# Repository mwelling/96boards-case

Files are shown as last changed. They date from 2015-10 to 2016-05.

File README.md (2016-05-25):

# 96boards-case

Files for making cases for 96Boards CE with 3D printers.

## File list

Open scad file, fits 96Boards CE

	96board-case.scad

STL file, fits 96Boards CE

	96board-case.stl

Open scad file, fits 96Boards CE with Mezzanine board

	96board-ce-mezzanine.scad

STL file, fits 96Boards CE with Mezzanine board

	96board-ce-mezzanine.stl

gcode file exported from stl file, fits 96Boards CE with Mezzanine board

Used for MUTOH MF-2000

	96board-ce-mezzanine.gcode

x3g file exported from stl file, fits 96Boards CE with Mezzanine board

Used for MakerBot Replicator 2X

	96board-ce-mezzanine.x3g

## Images

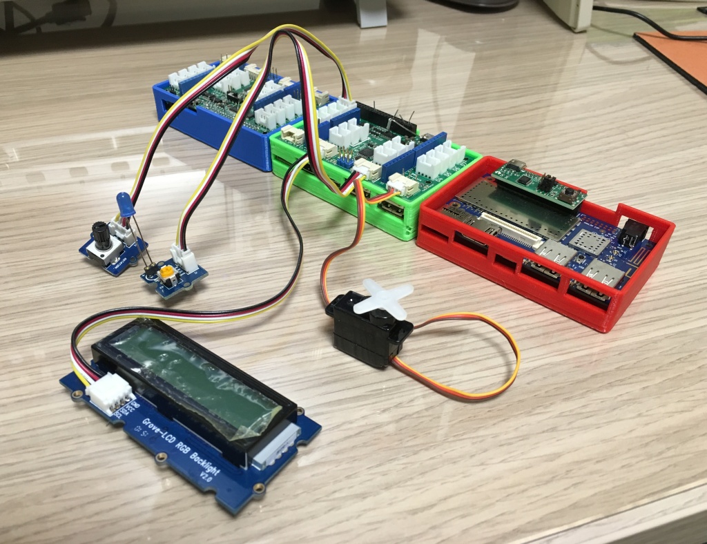
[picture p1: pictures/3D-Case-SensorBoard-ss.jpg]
All three cases

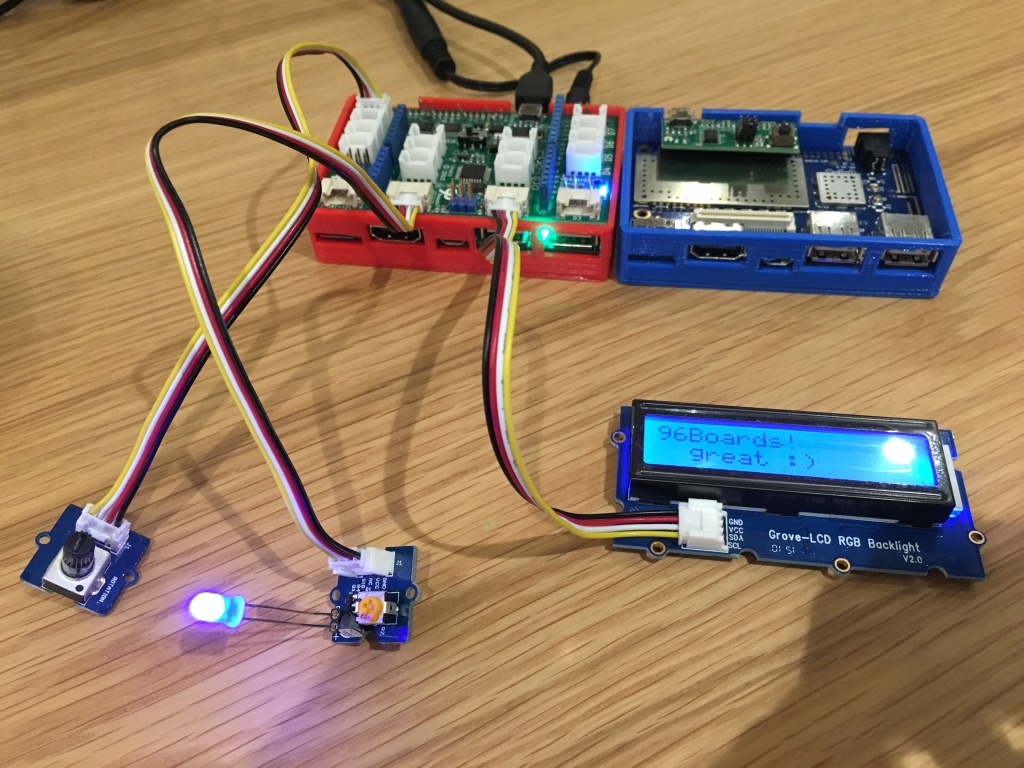
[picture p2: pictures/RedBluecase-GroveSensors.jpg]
With Grove Sensors

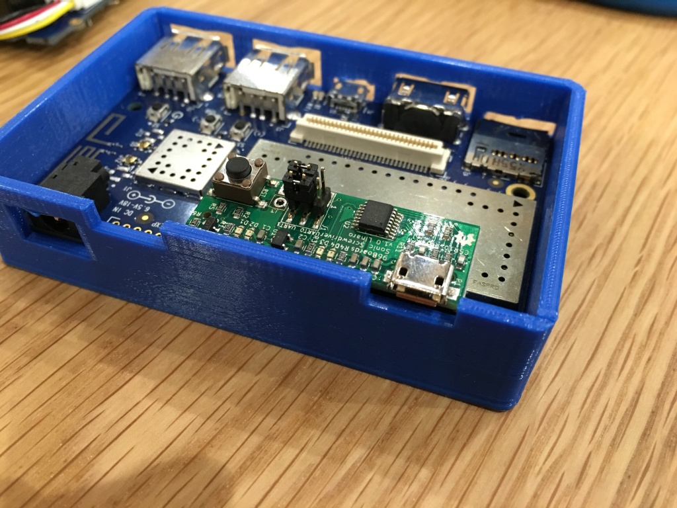
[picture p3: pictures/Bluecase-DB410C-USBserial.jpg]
USB-Serial-Blue

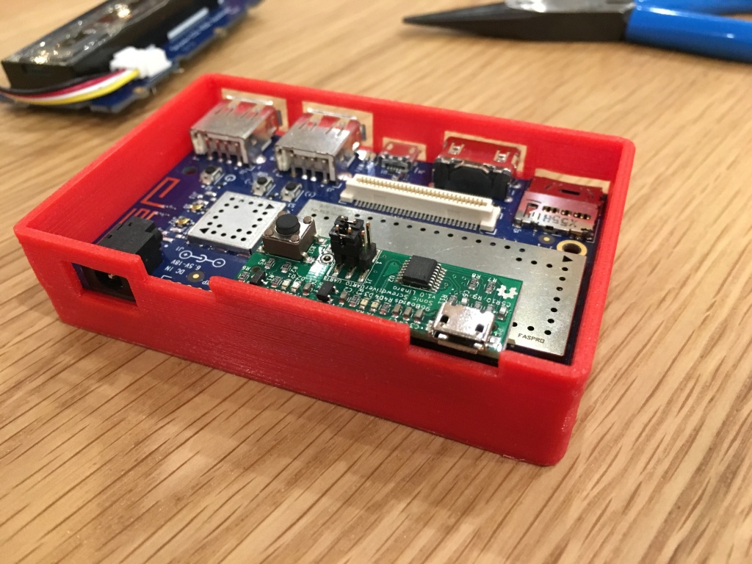
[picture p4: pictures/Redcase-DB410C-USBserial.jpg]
USB-Serial-Red

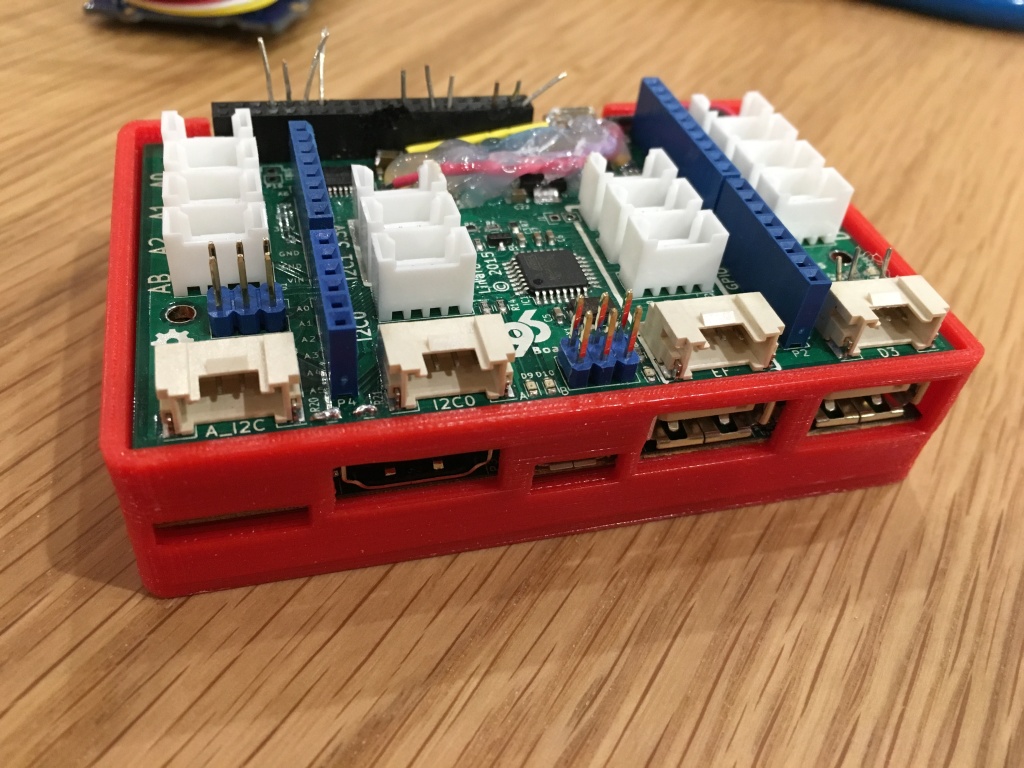
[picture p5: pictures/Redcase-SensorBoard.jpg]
SensorBoard

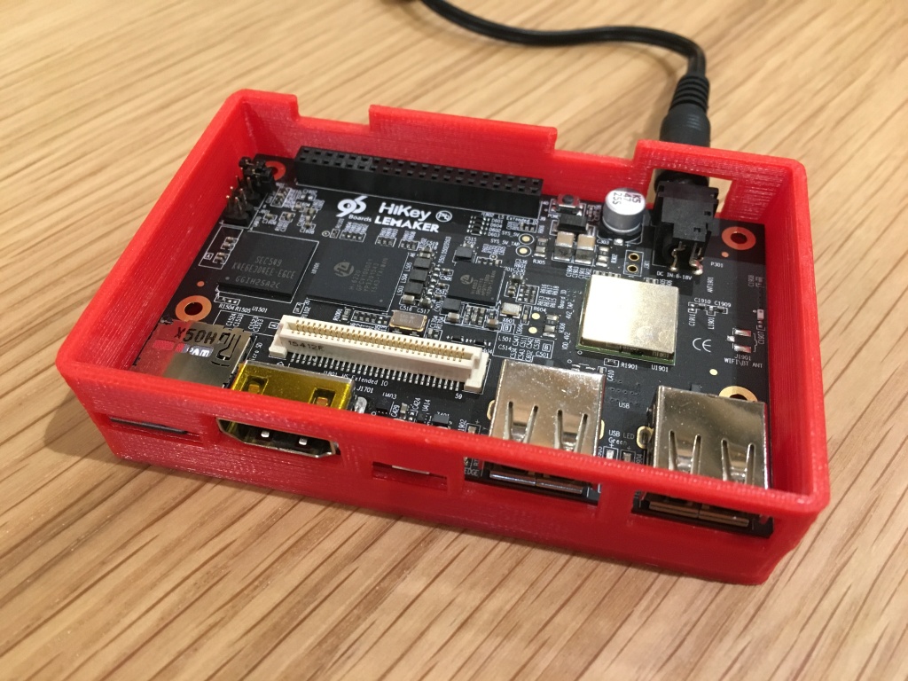
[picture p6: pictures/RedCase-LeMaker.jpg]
Red


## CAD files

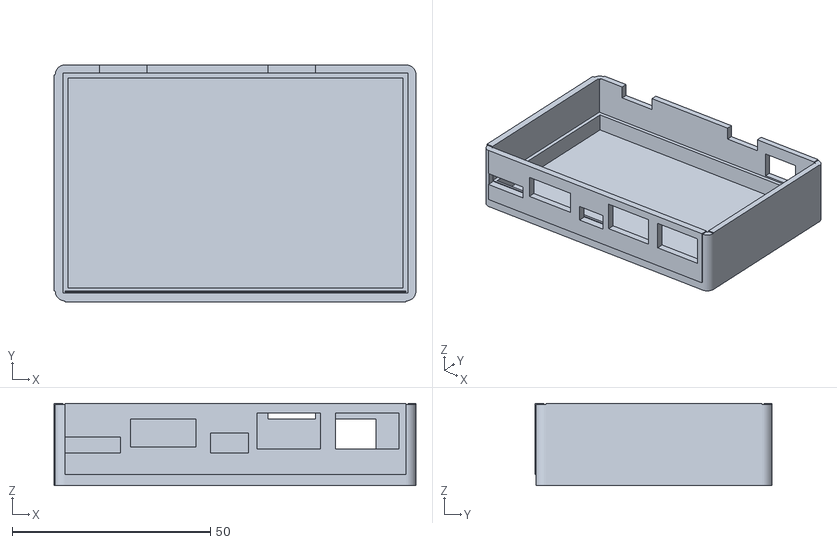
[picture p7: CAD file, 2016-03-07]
96board-ce-mezzanine.stl
91.4 x 59.9 x 20.8

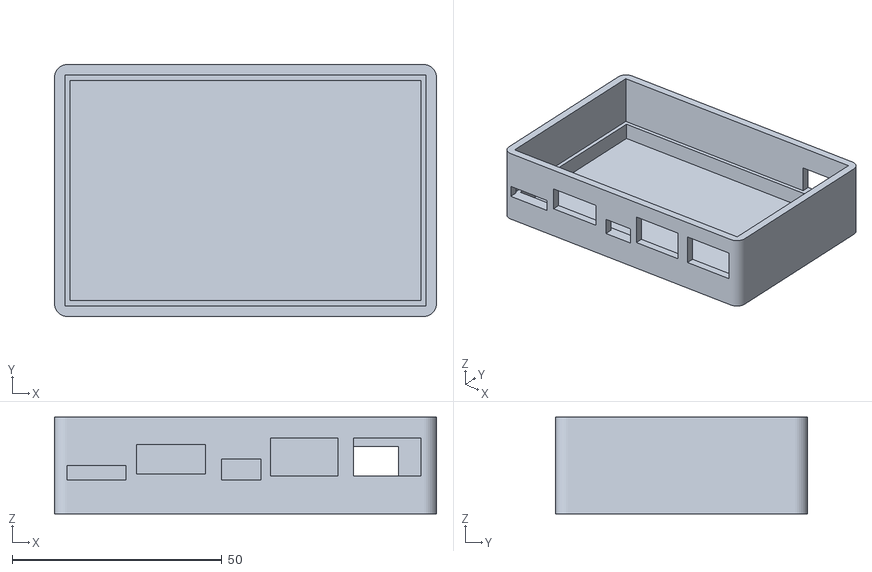
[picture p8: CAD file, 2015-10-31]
96board-case.stl
91.0 x 60.0 x 23.0

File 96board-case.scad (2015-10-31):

r = 2.0; /* connector relief */
l = 0.75; /* ledge thickness */ 
t = 3.0; /* thickness */
h = 20.0; /* height */
b = 5.0; /* bottom clearance */

difference() {
	union() {
		/* front face */
		difference() {
			translate([0, -t, -b]) {
				cube([85, t, h]);
			}
			union() {
				translate([1 - (r/2), -t, 1 - (r/2)]) {
					cube([12 + r, 15, 1.5 + r]);
				}
				translate([17.5 - (r/2), -t, 2.5 - (r/2)]) {
					cube([14.5 + r, 9, 5 + r]);
				}
				translate([37.75 - (r/2), -t, 1 - (r/2)]) {
					cube([7.5 + r, 5.25 , 3 + r]);
				}
				translate([49.5 - (r/2), -t, 2 - (r/2)]) {
					cube([14 + r, 14 , 7 + r]);
				}
				translate([69.25 - (r/2), -t, 2 - (r/2)]) {
					cube([14 + r, 14 , 7 + r]);
				}
			}
		}

		/* left face */
		intersection() {
			translate([0, 0, -b - t]) {
				cylinder(h = h + t, r1 = t, r2 = t, $fn = 36);
			}
			translate([-t, -t, -b - t]) {
				cube([t, t, h + t]);
			}
		}
		translate([-t, 0, -b - t]) {
			cube([t, 54, h + t]);
		}
		intersection() {
			translate([0, 54, -b - t]) {
				cylinder(h = h + t, r1 = t, r2 = t, $fn = 36);
			}
			translate([-t, 54, -b - t]) {
				cube([t, t, h + t]);
			}
		}

		/* right face */
		intersection() {
			translate([85, 0, -b - t]) {
				cylinder(h = h + t, r1 = t, r2 = t, $fn = 36);
			}
			translate([85, -t, -b - t]) {
				cube([t, t, h + t]);
			}
		}
		translate([85, 0, -b - t]) {
			cube([t, 54, h + t]);
		}
		intersection() {
			translate([85, 54, -b - t]) {
				cylinder(h = h + t, r1 = t, r2 = t, $fn = 36);
			}
			translate([85, 54, -b - t]) {
				cube([t, t, h + t]);
			}
		}

		/* back face */
		difference() {
			translate([0, 54, -b]) {
				cube([85, t, h]);
			}
			translate([69 - (r/2), 42 + t, 1 - (r/2)]) {
				cube([9 + r, 12 , 6 + r]);
			}
		}

		/* bottom face */
		translate([0, -t, -b - t]) {
			cube([85, 54 + 2*t, t]);
		}
	}

	translate([-.5, -.5, 0]) {
		cube([85+1, 54+1, h]);
	}

}

/* ledge */
difference() {
	translate([0, 0, -b]) {
		cube([85, 54, b]);
	}
	translate([l, l, -b]) {
		cube([85 - 2*l, 54 - 2*l, b]);
	}
}

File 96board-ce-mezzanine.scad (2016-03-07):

w = 85; /* width of 96Boards */
d = 54; /* depth of 96boaeds */

m = 0.6; /* margin for the plastic shrinking */

iw = w + m + 0.5; /* internal width, requires additional 0.5mm for LeMaker's HiKey, since LS connector has 0.5 offset */
id = d + m; /* internal depth */

r = 2.0; /* connector relief */
l = 0.75; /* ledge thickness */ 
t = 2.5; /* thickness 2mm is too thin, 3mm is too thick */
h = 18.0; /* height */
b = 5.5; /* bottom clearance */

it = t + (m/2); /* translate with margin */
im = (m/2); /* translate with margin */

difference() {
	union() {
		/* front face */
		difference() {
			translate([0, -it, -b]) {
				cube([iw, t, h]);
			}
			union() {
				translate([1 - (r/2), -it, 1 - (r/2)]) {
					cube([12 + r, 15 + im, 2 + r]);
				}
				translate([17.5 - (r/2), -it, 2.5 - (r/2)]) {
					cube([14.5 + r, 9 + im, 5 + r]);
				}
				translate([37.75 - (r/2), -it, 1 - (r/2)]) {
					cube([7.5 + r, 5.25 + im, 3 + r]);
				}
				translate([49.5 - (r/2), -it, 2 - (r/2)]) {
					cube([14 + r, 14 + im, 7 + r]);
				}
				translate([69.25 - (r/2), -it, 2 - (r/2)]) {
					cube([14 + r, 14 + im, 7 + r]);
				}
			}
		}

		/* left face */
		intersection() {
			translate([0, 0, -b - it]) {
				cylinder(h = h + t, r1 = t, r2 = t, $fn = 36 + im);
			}
			translate([-it, -it, -b - it]) {
				cube([t + im, t + im, h + t + im]);
			}
		}
		translate([-it, 0, -b - it]) {
			cube([t + im, id, h + t + im]);
		}
		intersection() {
			translate([0, id, -b - it]) {
				cylinder(h = h + t, r1 = t, r2 = t, $fn = 36 + im);
			}
			translate([-it, id, -b - it]) {
				cube([t + im, t, h + t + im]);
			}
		}

		/* right face */
		intersection() {
			translate([iw, 0, -b - it]) {
				cylinder(h = h + t, r1 = t, r2 = t, $fn = 36 + im);
			}
			translate([iw, -t, -b - it]) {
				cube([t, t, h + t + im]);
			}
		}
		translate([iw, 0, -b - it]) {
			cube([t, id, h + t + im]);
		}
		intersection() {
			translate([iw, id, -b - it]) {
				cylinder(h = h + t, r1 = t, r2 = t, $fn = 36 + im);
			}
			translate([iw, id, -b - it]) {
				cube([t, t, h + t + im]);
			}
		}

		/* back face */
		difference() {
			translate([0, id, -b]) {
				cube([iw, t, h]);
			}
			translate([67.5 - (r/2), 42 + it, 1.5 - (r/2)]) {
				cube([10 + r, 12 + im, 6 + r]);
			}
			translate([52.2 - (r/2), 42 + it, 9.5 - (r/2)]) {
				cube([10 + r, 19 + im, 6 + r]);
			}
			translate([9.7 - (r/2), 42 + it, 9.5 - (r/2)]) {
				cube([10 + r, 19 + im, 6 + r]);
			}
		}

		/* bottom face */
		translate([0, -t, -b - it]) {
			cube([iw, id + 2*t, t + im]);
		}
	}

	translate([-.5, -.5, 0]) {
		cube([iw+1, id+1, h]);
	}

}

/* ledge */
difference() {
	translate([0, 0, -b]) {
		cube([iw, id, b]);
	}
	translate([l, l, -b]) {
		cube([iw - 2*l, id - 2*l, b]);
	}
}

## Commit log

2015-10-13 Initial commit of OpenSCAD and STL files for case
    [96board-case.scad, 96board-case.stl, 96board.scad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]
2015-10-24 Remove less than accurate models of the PCB
    [96board.scad, 96board.stl]
2015-10-24 Updates based on first prints
    Adds .5mm around the diameter of the board so it actaully fits the case.
    Adjusts the locations and sizes of the holes for the connectors.
    [96board-case.scad, 96board-case.stl]
2015-10-24 Move the wrong USB connector
    Actually notice when looking at the graphical diff on github.
    Now it is print worthy.
    [96board-case.scad, 96board-case.stl]
2015-10-24 Minor tweaks
    The connector holes should be closer to center now. I hope.
    [96board-case.scad]
2015-10-24 Push tweaks to model
    Them holes just don't want to line up.
    [96board-case.stl]
2015-10-24 I need to get my eyes checked
    Cross your fingers before printing.
    [96board-case.scad, 96board-case.stl]
2015-10-31 Move HDMI connector hole up slightly
    [96board-case.scad]
2015-10-31 Update formatting on scad model and export stl
    [96board-case.scad, 96board-case.stl]
2016-03-01 Open scad file, fits 96Boards CE with Mezzanine board
    [96board-ce-mezzanine.scad]
2016-03-01 STL file, fits 96Boards CE with Mezzanine board
    [96board-ce-mezzanine.stl]
2016-03-01 gcode file exported from stl file, fits 96Boards CE with Mezzanine board
    Optimized for MUTOH MF-2000.
2016-03-01 x3g file exported from stl file, fits 96Boards CE with Mezzanine board
    Optimized for MakerBot Replicator 2X
2016-03-01 adding picture of DB410C with Mezzanine-USB-serial in red case
2016-03-01 adding picture of DB410C with Mezzanine USB serial in blue case
2016-03-01 adding picture of HiKey in red case
2016-03-01 adding picture of HiKey with Sensor Boards in red case
